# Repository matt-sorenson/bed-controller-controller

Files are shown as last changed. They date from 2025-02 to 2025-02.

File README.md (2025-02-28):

# bed-controller-controller

This controls a Richmat HJH89 remote control that came with my bed but should work for any remote.

It has 3 memory buttons that are controlled by the ESP32-C6 controller (zg (zero-g), sit-up (memory) & flat)

I didn't include the massage buttons, underbed light, lumbar or head tilt as I never used them.

The switchs controlling the Head Up/Down & Feet Up/Down are not controllable from the ESP as the delay made it hard to actually get it to a possition you want.

## Parts List

1x [Bed Remote](https://svenandson.com/products/sven-son-replacement-remote?variant=32488578908238)
3x [Relays](https://www.digikey.com/en/products/detail/te-connectivity-potter-brumfield-relays/1462041-7/2126941)
3x [Transistors](https://www.digikey.com/en/products/detail/diodes-incorporated/MMBT3904-7-F/814494)
1x [Seeed Studio XIAO ESP32-C6](https://www.seeedstudio.com/Seeed-Studio-XIAO-ESP32C6-p-5884.html)
7x Cherry-MX Keyswitches
7x relegendable keycaps (the ones pictures were random purchase from amazon, trying laser engraving blank black keycaps when I can)
1x 2-pin picoblade inline male (power cable)
1x 2-pin picoblade inline female (power cable)
1x 6-pin picoblade inline male
1x 6-pin picoblade inline female
1x 8-pin picoblade inline male
1x 8-pin picoblade inline female

### Notes

- it doesn't matter which set of pins are connected with the 6 or 8 pin, just make sure you wire them to the correct contacts on the OEM remote.
- For my OEM Remote PCB I rounded the corners of the PCB with sandpaper, needed within the provided case but no real functional reason.

## Pictures along the way

Board with all parts soldered on.

### Top of board with components soldered in place

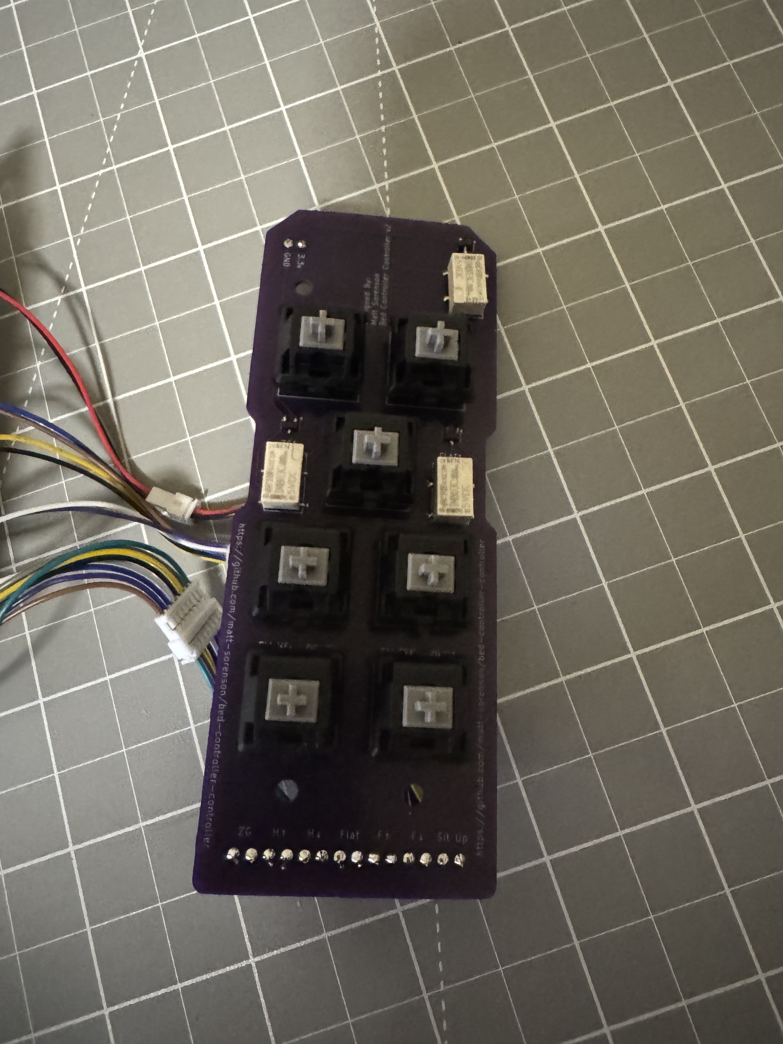
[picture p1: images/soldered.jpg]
soldered


### Bottom of board with components & wires soldered in place along with OEM remote

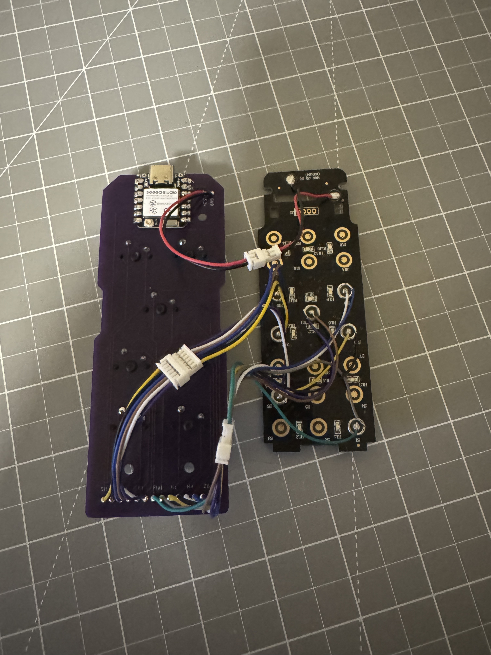
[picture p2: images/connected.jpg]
wires connected


### PCBs placed inside the case

The foam block is a cube from [this sheet](https://www.mcmaster.com/catalog/131/4104/3157T23). It keeps the OEM PCB in place as there's no good place to put a screw through that PCB.

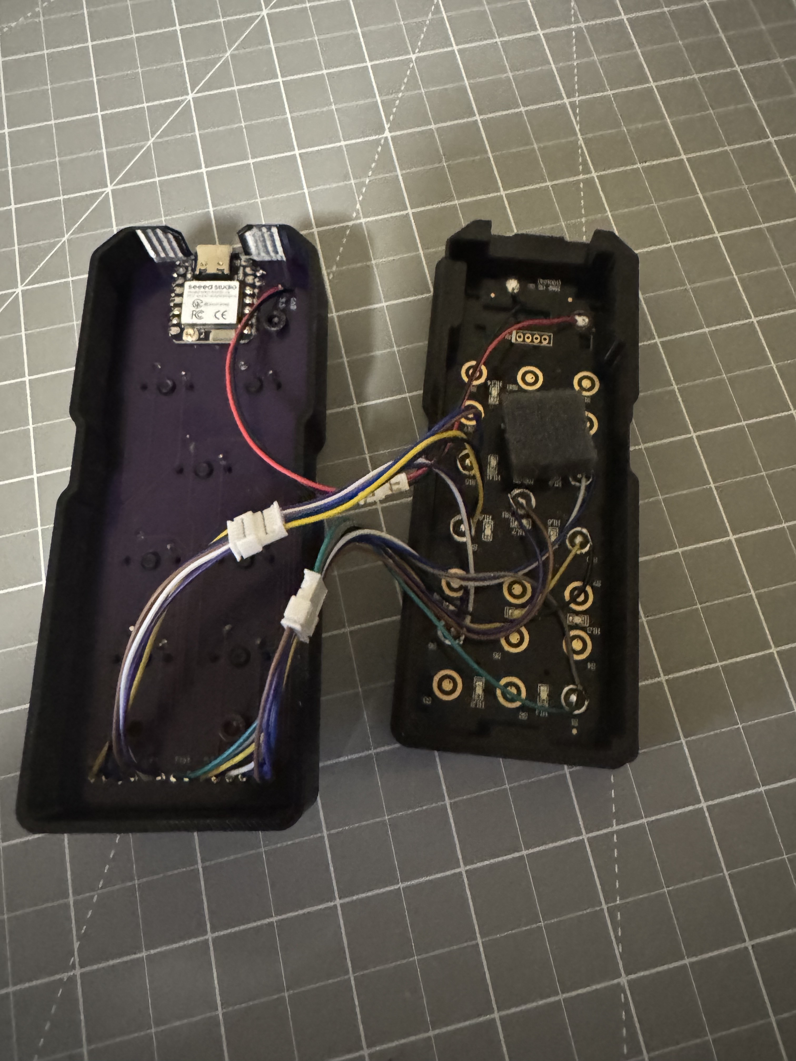
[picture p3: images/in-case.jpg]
case internals


### Completed Assembly

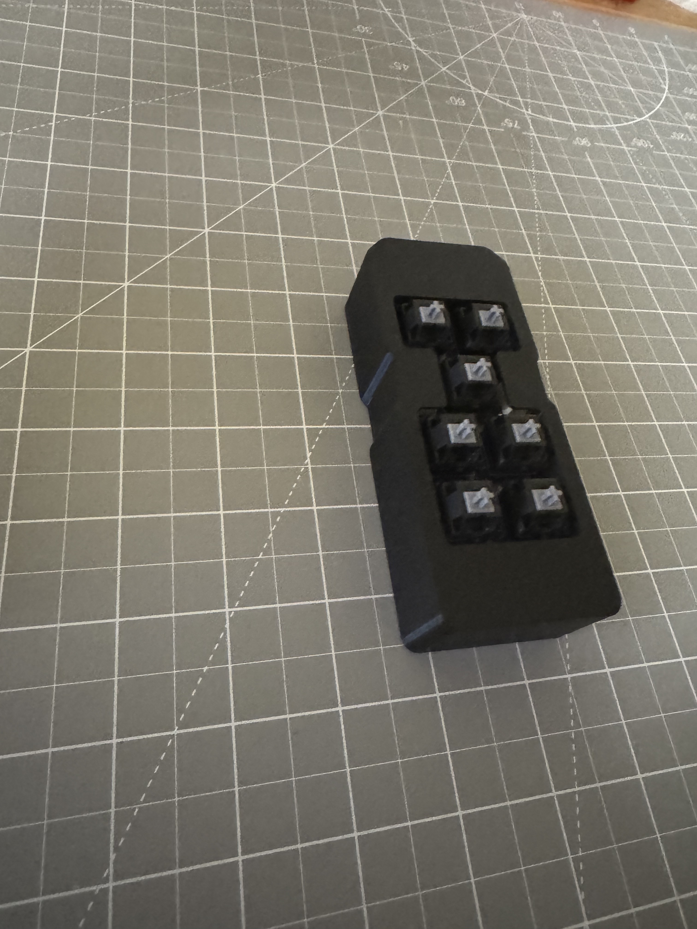
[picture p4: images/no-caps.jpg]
assembled without keycaps

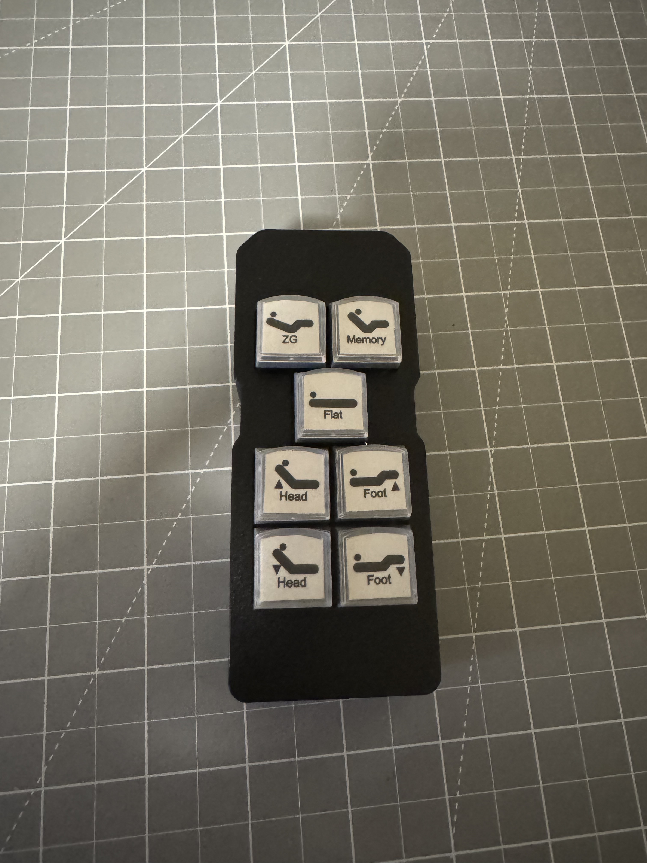
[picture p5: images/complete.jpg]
assembled


Don't know how I got so lucky on the clearances but my print of the case stays together well but is easy enough to take back apart.

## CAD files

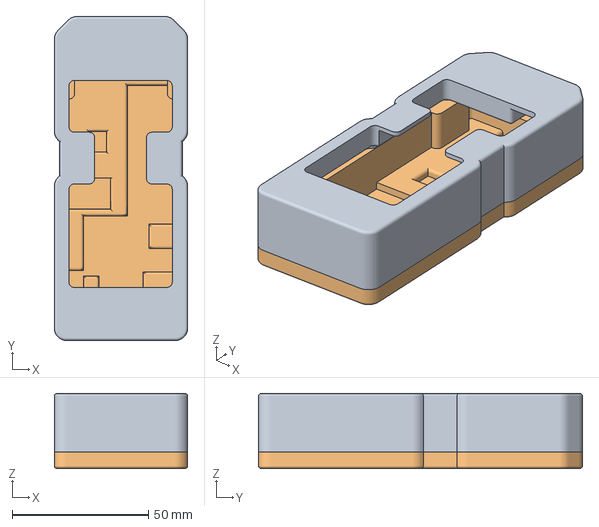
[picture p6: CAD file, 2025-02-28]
Case v27.3mf
49.0 x 119.0 x 27.6 mm

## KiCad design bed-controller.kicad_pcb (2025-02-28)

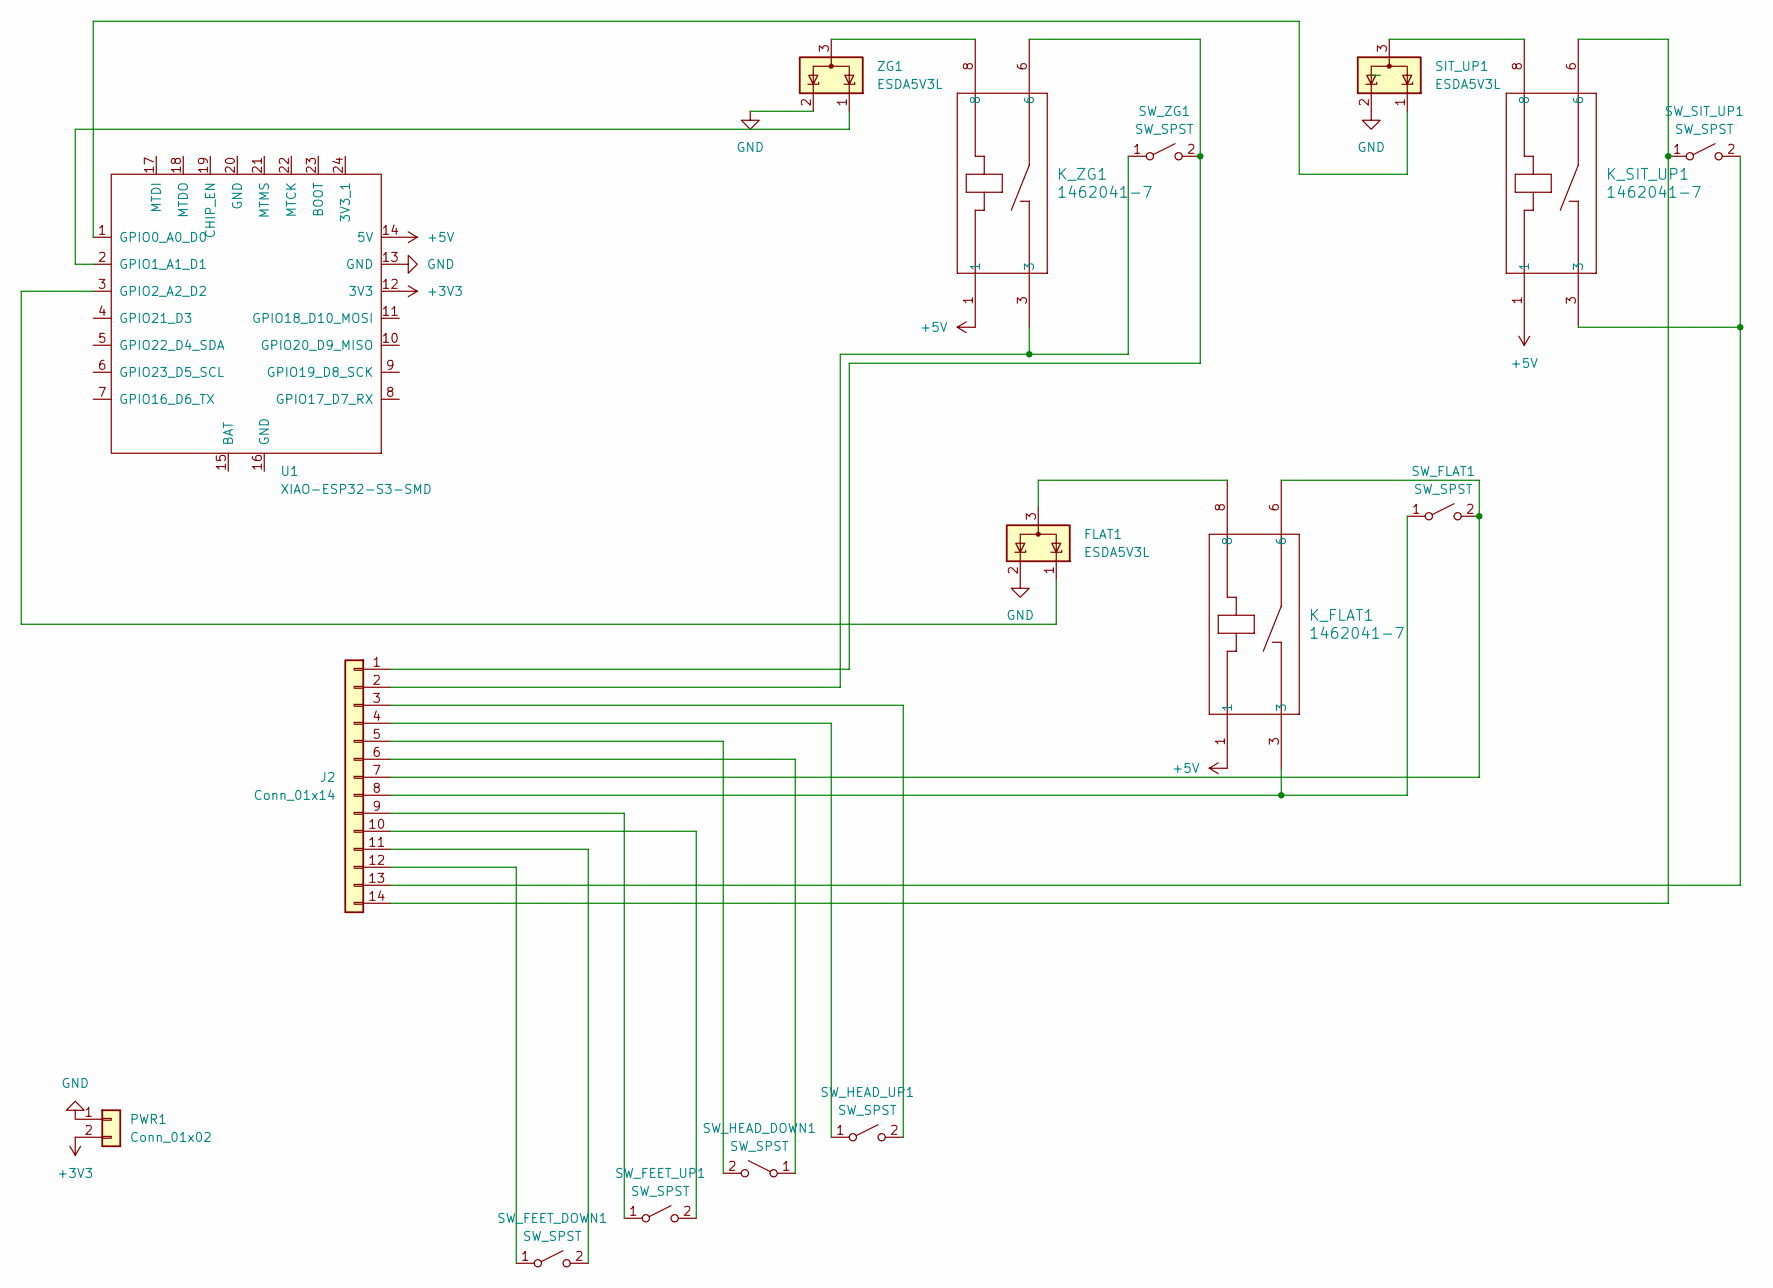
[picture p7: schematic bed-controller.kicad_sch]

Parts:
FLAT1: ESDA5V3L; SOT-23-3
J2: Conn_01x14; PinHeader_1x14_P2.54mm_Vertical
K_FLAT1: 1462041-7; bigger-pads-RELAY4_1462041-7_TEC
K_SIT_UP1: 1462041-7; bigger-pads-RELAY4_1462041-7_TEC
K_ZG1: 1462041-7; bigger-pads-RELAY4_1462041-7_TEC
PWR1: Conn_01x02; PinHeader_1x02_P2.54mm_Vertical
SIT_UP1: ESDA5V3L; SOT-23-3
SW_FEET_DOWN1: SW_SPST; center-SW_Cherry_MX_1.00u_PCB
SW_FEET_UP1: SW_SPST; center-SW_Cherry_MX_1.00u_PCB
SW_FLAT1: SW_SPST; center-SW_Cherry_MX_1.00u_PCB
SW_HEAD_DOWN1: SW_SPST; center-SW_Cherry_MX_1.00u_PCB
SW_HEAD_UP1: SW_SPST; center-SW_Cherry_MX_1.00u_PCB
SW_SIT_UP1: SW_SPST; center-SW_Cherry_MX_1.00u_PCB
SW_ZG1: SW_SPST; center-SW_Cherry_MX_1.00u_PCB
U1: XIAO-ESP32-S3-SMD; XIAO-ESP32C6-SMD-bigger-pads
ZG1: ESDA5V3L; SOT-23-3

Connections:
+3V3: PWR1.2, U1.12 (3V3)
+5V: K_FLAT1.1, K_SIT_UP1.1, K_ZG1.1, U1.14 (5V)
GND: FLAT1.2 (K), PWR1.1, SIT_UP1.2 (K), U1.13 (GND), ZG1.2 (K)
unnamed: FLAT1.3 (A), K_FLAT1.8
unnamed: J2.1, K_ZG1.6, SW_ZG1.2 (B)
unnamed: J2.2, K_ZG1.3, SW_ZG1.1 (A)
unnamed: J2.3, SW_HEAD_UP1.2 (B)
unnamed: J2.4, SW_HEAD_UP1.1 (A)
unnamed: J2.5, SW_HEAD_DOWN1.2 (B)
unnamed: J2.6, SW_HEAD_DOWN1.1 (A)
unnamed: J2.7, K_FLAT1.6, SW_FLAT1.2 (B)
unnamed: J2.8, K_FLAT1.3, SW_FLAT1.1 (A)
unnamed: J2.9, SW_FEET_UP1.1 (A)
unnamed: J2.10, SW_FEET_UP1.2 (B)
unnamed: J2.11, SW_FEET_DOWN1.2 (B)
unnamed: J2.12, SW_FEET_DOWN1.1 (A)
unnamed: J2.13, K_SIT_UP1.3, SW_SIT_UP1.2 (B)
unnamed: J2.14, K_SIT_UP1.6, SW_SIT_UP1.1 (A)
unnamed: K_SIT_UP1.8, SIT_UP1.3 (A)
unnamed: SIT_UP1.1 (K), U1.1 (GPIO0_A0_D0)
unnamed: U1.2 (GPIO1_A1_D1), ZG1.1 (K)
unnamed: FLAT1.1 (K), U1.3 (GPIO2_A2_D2)
unnamed: K_ZG1.8, ZG1.3 (A)

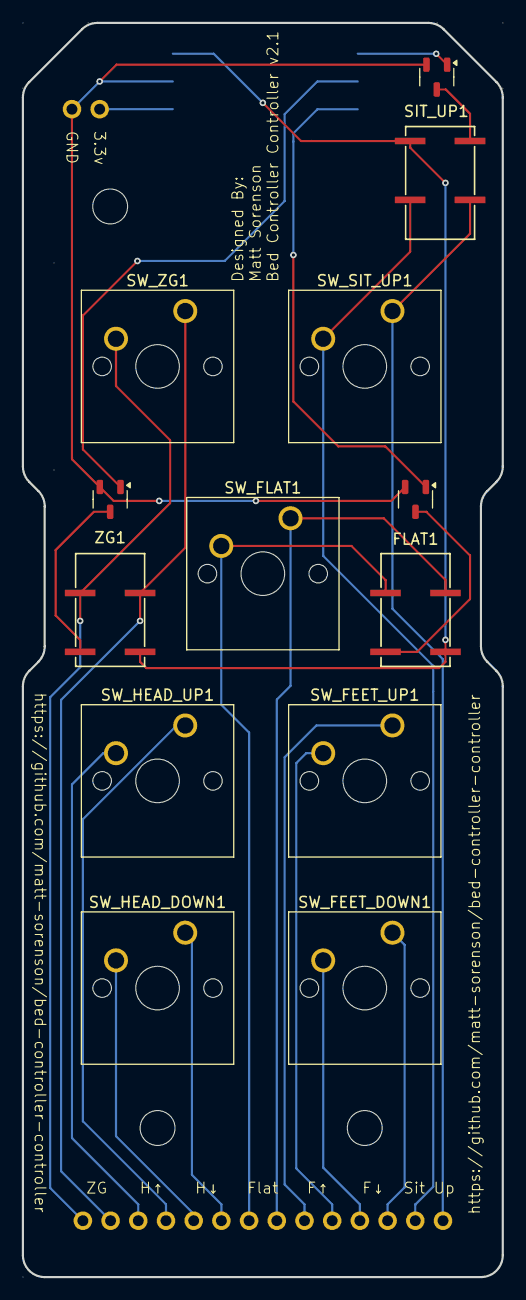
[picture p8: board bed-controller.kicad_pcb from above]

Board: 2 copper layers, 44.0 x 115.0 mm, 16 parts (1 on the bottom side), 23 nets.

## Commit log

2025-02-28 v1 gerber files
2025-02-28 v2 gerber files
2025-02-28 v2.1 kicad project & gerber files
    [bed-controller.kicad_pcb, bed-controller.kicad_sch]
2025-02-28 remove gerber files
2025-02-28 3mf file to hold PCB & the OEM board from bed.
    [Case v27.3mf]
